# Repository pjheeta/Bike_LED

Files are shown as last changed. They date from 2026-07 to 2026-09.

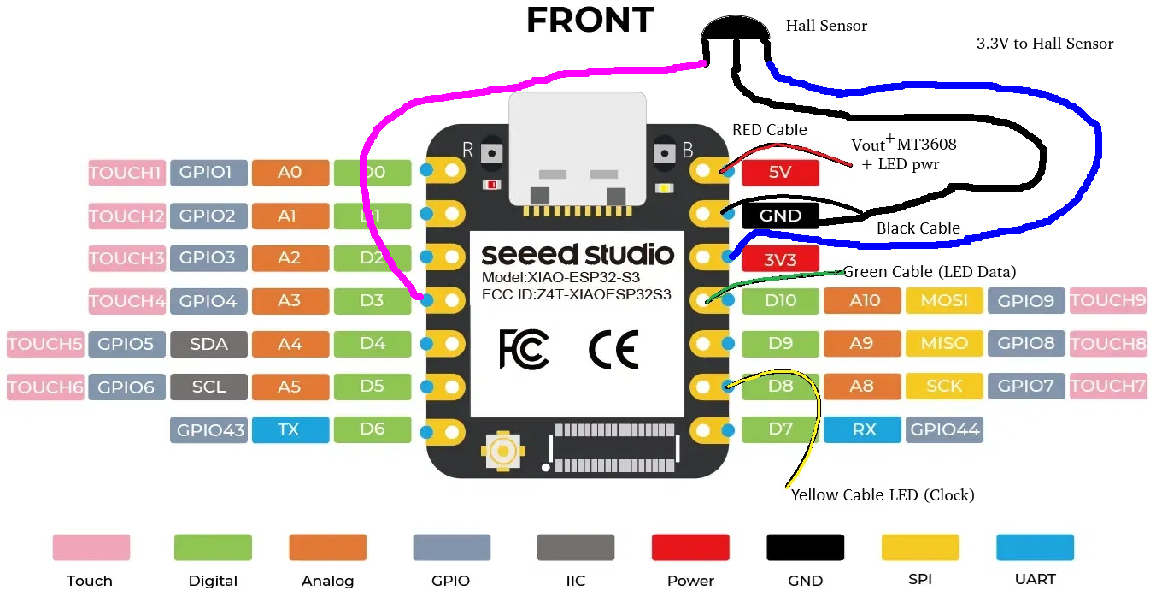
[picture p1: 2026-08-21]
ESP32S3 LED Pinout connection.jpg

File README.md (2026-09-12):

# Burning Man LED Wheel

<p align="center">
  Spinning LED wheel animation
</p>

<p align="center">
  Super cool Burning Man wheel LEDs inspired by:
</p>
<p align="left">
  - <a href="https://www.youtube.com/watch?v=W3Gmv9J05eQ">Monkey Lights POV</a>
</p>
<p align="left">
  - Luca Schultz's project <a href="https://github.com/BikeBeamer/BikeBeamer">BikeBeamer</a> 
</p>
<p align="left">
  - Adafruit Industries <a href="https://learn.adafruit.com/bike-wheel-pov-display/prep-leds-and-breadboard?view=all">BikeWheel POV Display with Pro Trinket</a> 
</p>

---

# Burning Man 2026 Update

<b>The project was a partial failure</b>
- The POV (Persistence of Vision) system did not work.   The Magnet / Hall Sensor Solution was a horrible Idea.    The magnets were not strong enough to trigger the hall sensor and mounting Magnets to the Bike was not practical.
- The industrial ABS boxes could not be secured with even two industrial strength zip ties.    The Playa was not an even ground and the the force of the bike wheels hitting the Playa released the boxes from the zip ties,  resulting in the ABS boxes from being ejected from the bike, and causing the wires to be broken. 
- The 26 AWG wires constantly broke, expecially from the Strip to Strip connecitons.   Detailed soldering on the Playa was not possible, and it was tiem consuming. 
- ESP Wi-Fi was not operational while using the LIPO batteries.   Wi-Fi worked with USB powered circuits, however I failed to test the completed system  powered by the Lipo batteres.    1 day before leaving for the burn, I relized the circuit required additioanl capaitors to power the circuit with the LIPO batteries.   I did not have a time to implement this, thus I had uploaded a 20 random patterns per bike wheel circuit to appear whenever the Bike LED system was turned on.

<b>Future changes to the system</b>
- 3D print the the enclosures and the LED Strips to directly attach to the bike spokes
- Use a Gyroscope, to measue rotations, eliminating the magnet
- Make the system modulate.     Do not rely on soldering connecitons, instead use physical connectors.   If the LED strips fails, it can easily be swapped out for a working one.

## ---

# Overview

POV (Persistence of Vision) LED display for a bike wheel. Animated images appear to float in the spinning wheel, visible from both sides. Controlled via WiFi from your phone — no app needed, although an Android app was created.

This project began withThis pdea of only having one LED strip per side. However, you would need to bike in excess of 20 mph to generate a stable image. Since this project was built for Burning Man, where the max speed is 5 mph on the playa, a single LED strip per arm wouldn't work.

After consulting with Luca Schultz (BikeBeamer builder), the design changed to **4 arms per wheel** with LED strips on both faces of each arm — 8 LED strips per wheel total. At around 5 mph, the image flashes 4 times per rotation, making basic shapes such as squares, circles, and the Man himself clearly visible.

My project uses a Vivi e-bike with 27.5" wheels. The **front wheel** uses LED strips with 144 LEDs/meter for maximum resolution, while the **back wheel** uses LED strips with 30 LEDs/meter for ambient glow patterns. Maybe in Burning Man 2027, both wheels will use the same LED counts.

⚠️ **Both Wheels are different!** The front wheel allows a longer LED strip. Due to e-bike design, the rear wheel has the hub motor — which means the distance from the hub to the rim is shorter. Henceforth, the spoke geometry is different, giving a shorter strip on the back wheel.

This version of Bike LED is for the 2026 Burning Man. A new repository will be created for the 2027 Burning Man project.

---

## Hardware

| Component | Notes |
|---|---|
| 2x XIAO ESP32-S3 | Main controller — WiFi + MicroPython. One per wheel. |
| SK9822 LED strips (144 LEDs/m) | Black PCB, IP30 — Front wheel: 8 strips × 27 LEDs = 216 LEDs total |
| SK9822 LED strips (30 LEDs/m) | Black PCB, IP30 — Rear wheel: 8 strips × 7 LEDs = 56 LEDs total |
| 3x LiPo 3.7V 2000mAh | 2x per front wheel (parallel for more capacity) + 1x rear wheel. All removable nightly for charging via JST connector. |
| 3x TP4056 USB-C | LiPo charger with protection circuit — one per battery |
| 2x MT3608 boost converter | Steps 3.7V LiPo up to 5.07V for LEDs and XIAO. LEDs require 5V to operate correctly. |
| 2x A3144 hall effect sensor | Rotation sync — fires one interrupt per revolution via falling edge trigger |
| 2x 1N5400 Schottky diode | One per positive wire on front wheel parallel battery pair — prevents cross-charging between batteries if voltage mismatch is present |
| 2x 6mm neodymium magnet | Mounts on fork dropout (stationary), triggers hall sensor once per rotation |
| 8x Aluminum flat bar 1/8" × 1/2" | LED arm material. Length depends on spoke measurement — cut after measuring actual bike. 4 per wheel. |
| 2x ABS enclosure 80×50×26mm | Hub-mounted via velcro + zip tie, houses all electronics |
| 2x SPST rocker switch 10×15mm | Kill switch — mounted on long side wall of enclosure |
| Kapton/polyimide tape | Applied between LED strip and aluminum bar to prevent electrical shorts |
| Velcro straps 3/4" | Secures enclosure to hub, secures components inside enclosure |
| Zip ties | Secures LED arms to spokes at hub end and rim end |
| Hot glue | Seals wire exit holes against playa dust |
| MG Chemicals 419D | Conformal coat — applied to all boards after testing is complete |

---

## Four-Arm Design

Both wheels use the same 4-arm layout — arms mounted at 90° intervals around the wheel, giving 4 image flashes per rotation at playa speed.

```
        ARM 1 (0°)
    ● ● ● ● ● ● ●      ← LEDs face right (A face)
    ═══════════════     ← Aluminum bar
    ● ● ● ● ● ● ●      ← LEDs face left  (B face — reversed in firmware)
            │
ARM 4 ══ HUB ══ ARM 2   ← XIAO + battery enclosure velcro'd to hub
            │
        ARM 3 (180°)
```

### Front Wheel — 144 LEDs/m

- **4 arms** at 90° apart
- **2 strips per arm** — A face (front) and B face (back)
- **27 LEDs per strip** at 144/m = 187mm (~7.4") per arm
- **216 LEDs total** across 8 strips
- **Daisy chain order:** XIAO → A1(1-27) → B1(28-54) → A2(55-81) → B2(82-108) → A3(109-135) → B3(136-162) → A4(163-189) → B4(190-216)

**LED table:**

| Strip | Start LED | End LED | Arm | Face |
|---|---|---|-----|---|
| A1 | 1 | 27 | Arm 1 | Front |
| B1 | 28 | 54 | Arm 1 | Back (reversed) |
| A2 | 55 | 81 | Arm 2 | Front |
| B2 | 82 | 108 | Arm 2 | Back (reversed) |
| A3 | 109 | 135 | Arm 3 | Front |
| B3 | 136 | 162 | Arm 3 | Back (reversed) |
| A4 | 163 | 189 | Arm 4 | Front |
| B4 | 190 | 216 | Arm 4 | Back (reversed) |

⚠️ **Back face strips (B1, B2, B3, B4) must be reversed in firmware.** The B strip runs rim → hub (opposite direction to the A strip), so the image would appear upside down without reversal. This is handled automatically in `frames.py` via `list(reversed(...))`.

**Animations:** Circle, square, cross, rainbow — simple geometric shapes chosen specifically because they are symmetric (look identical from both sides of the wheel) and clearly visible at 5 mph playa speeds.

---

### Rear Wheel — 30 LEDs/m

- **4 arms** at 90° apart
- **2 strips per arm** — A face (front) and B face (back)
- **7 LEDs per strip** at 30/m = ~233mm per arm
- **56 LEDs total** across 8 strips
- **Purpose:** Ambient glow and simple patterns — not detailed POV images
- Rear wheel has hub motor which shortens effective spoke length vs front wheel
- At 30 LEDs/m resolution is too low for detailed images — but rainbow, solid color, and simple shapes look great at any speed

**Powered by:** 1x 2000mAh LiPo — lighter draw than front wheel, single battery is sufficient.

---

## Power Architecture

⚠️ **Two completely separate circuits — never combine them.**

**Riding circuit (wheel spinning):**
```
LiPo → [1N5400 diode] → MT3608 (5.07V) → XIAO + LED strips
```
*(Front wheel: 2x LiPo in parallel via diodes. Rear wheel: single LiPo, no diodes needed.)*

**Charging circuit (parked at camp):**
```
USB-C wall charger → TP4056 → LiPo battery
```
The TP4056 is **never** in the riding circuit. Each LiPo unplugs via JST connector for individual overnight charging.

---

## Burning Man Notes

- **Balance** — mount battery as close to hub center as possible to minimize vibration
- **Don't tap the e-bike battery** — keep LED system on its own LiPo, modular and safe
- **Nightly charging** — LiPo velcro-mounts to enclosure floor, unplugs via JST in seconds
- **Playa-proof** — hot glue all wire exits, apply MG Chemicals 419D conformal coat to all boards after testing
- **Kill switch** — rocker switch on enclosure wall cuts all power instantly
- **Safety mode** — if hall sensor stops triggering, firmware automatically switches to alternating white safety LEDs

---

## Built With

- MicroPython
- Thonny (MicroPython Code IDE)
- VS Code
- MarkEdit and the home extension MarkView
- Cool people such as Luca (BikeBeamer)
- Blood, sweat, and tears
- claude.ai for tips, explanation, lessons, and making me order the wrong parts
- [StackEdit](https://stackedit.io/) for this README

---

## Files

| File | Purpose |
|---|---|
| `main.py` | Main loop — WiFi server + POV timing. Auto-runs on boot |
| `apa102.py` | SPI driver for SK9822/APA102 LED strip |
| `hall_sync.py` | Hall sensor interrupt handler — measures rotation period |
| `frames.py` | Frame data — circle, square, cross, rainbow animations |
| `convertImage.py` | Laptop-side script — converts PNG to `frames.py` format |
| `BOM.txt` | Full bill of materials with sources and prices |

**main.py flow:**
```
Boot → Start WiFi + Web Server
         ↓
Loop → Check web requests every 100ms
         ↓
      Wheel spinning? No → LEDs off (safety)
         ↓ Yes
      Get rotation period from hall sensor
         ↓
      Display 60 columns timed to rotation speed
         ↓
      Repeat forever
```

**apa102.py SPI chain:**
```
XIAO GPIO9 (MOSI) ──→ DI ──→ LED 1 ──→ LED 2 ──→ ... ──→ LED 216
XIAO GPIO7 (SCK)  ──→ CI ──→ LED 1 ──→ LED 2 ──→ ... ──→ LED 216

Every strip.show() call sends:
[00 00 00 00]        ← Start frame — "attention LEDs!"
[FF bb gg rr]        ← LED 1 color (4 bytes — note B,G,R order not R,G,B)
...repeat per LED...
[FF FF FF FF...]     ← End frame — "that's all!"
```

**hall_sync.py flow:**
```
Magnet passes sensor
        ↓
Pin goes HIGH → LOW (falling edge)
        ↓
Hardware interrupt fires instantly
        ↓
_on_trigger() records timestamp + period + count
        ↓
main.py reads period_us → calculates column timing
main.py reads rotation_count → advances animation frame
main.py calls is_spinning() → decides whether to show LEDs
```

---

## WiFi Control

The XIAO acts as its own WiFi access point — no internet or router needed.

1. Connect phone to **BikeWheel** network (password: `burningman`)
2. Open Android app or browser → `192.168.4.1`
3. Control on/off, brightness, speed, safety mode, select animation frame

---

## Animation Frames

Originally planned: Nyan Cat, Angine de Poitrine polka dot mask, Joe's face.

After consulting with Luca (BikeBeamer) and calculating that 5 mph playa speed only gives ~1 rotation/second with a single arm, the design changed to 4 arms and simple geometric shapes that read clearly at low flash rates:

- 🔴🔵 **Test pattern** — alternating red/blue columns (confirms POV timing)
- ⭕ **Circle** — glowing cyan ring floating in the wheel
- 🟧 **Square** — orange square outline
- ✚ **Cross** — pink plus sign
- 🌈 **Rainbow** — full color waterfall, works at any speed

Images will still be added for testing and showing off to people at camp. 😄

---

## Image Conversion Pipeline

Design artwork at **60 × 27 pixels** in any image editor → run `convertImage.py` on laptop → upload `frames.py` to XIAO via Thonny → image appears on spinning wheel.

---

## License

MIT

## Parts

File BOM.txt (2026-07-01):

XIAO ESP32-S3 (x2) — search: Seeed Studio XIAO ESP32S3 — ~$10-13 each

LiPo Battery 3.7V 2000mAh (x2) — search: 3.7V 2000mAh LiPo flat battery JST connector — ~$8-12 each

TP4056 Charger Board (x2) — search: TP4056 charging module with protection — ~$1-2 each

MT3608 Boost Converter (x2) — search: MT3608 DC-DC boost converter module — ~$1-2 each

Hall Effect Sensor A3144 (pack of 10) — search: A3144 hall effect sensor module — ~$5-7

Neodymium Disc Magnets 6mm (pack of 20) — search: 6mm x 2mm neodymium disc magnets — ~$6-8

Carbon Fiber Flat Strip — search: carbon fiber flat strip 3mm 300mm — ~$10-15

MG Chemicals 419D Conformal Coat — search: MG Chemicals 419D conformal coating — ~$15-18

Silicone Wire 24 AWG — search: 24 AWG silicone wire kit multicolor — ~$8-10

JST-SH Connectors — search: JST SH 1.0mm connector kit — ~$8-10

Heat Shrink Tubing — search: heat shrink tubing assorted sizes kit — ~$8-10

Kill Switch (add both — button for riding, rocker for hard off)

Momentary Tactile Push Button (pack of 20) — search: 6mm momentary tactile push button switch — ~$5 | Mounts on hub enclosure, one-handed toggle while riding

Mini Rocker Switch (pack of 10) — search: mini rocker switch ON OFF SPST 3A — ~$7 | Hard power cut on the power line, no reboot needed if wired after TP4056

SK9822 LED Strip, 5m, Black PCB, IP30 
Slip ring, 6-wire, 2A/channel (metal housing preferred)

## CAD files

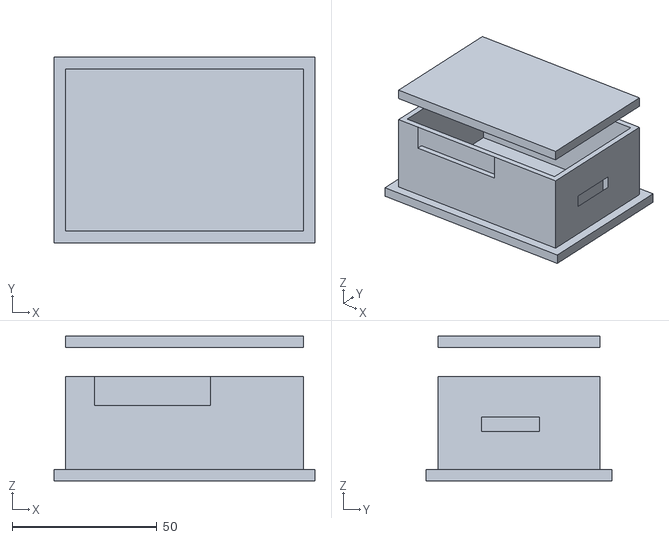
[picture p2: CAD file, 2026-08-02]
Hardware/bikewheel_enclosure.stl
90.0 x 64.0 x 50.0

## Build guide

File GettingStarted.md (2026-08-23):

# BikeWheel Project — Command Reference
## Pawan Heeta | Burning Man 2026

---

## 1. LINUX SETUP (Ubuntu/Mint)

### Add user to dialout group (fixes USB permission errors)
```bash
sudo usermod -a -G dialout $USER
# Then reboot
```

### Add esptool to PATH
```bash
echo 'export PATH=$PATH:~/Library/Python/3.9/bin' >> ~/.zshrc
source ~/.zshrc
```

### Install esptool
```bash
pip3 install esptool --break-system-packages
esptool.py version  # confirm 4.12.0+
```

---

## 2. FLASHING MICROPYTHON FIRMWARE

### Download firmware
- URL: https://micropython.org/download/SEEED_XIAO_ESP32S3/
- Get latest preview .bin file

### Put XIAO in bootloader mode
1. Hold BOOT button
2. Press and release RESET
3. Release BOOT

### Flash firmware
```bash
# Erase first
esptool.py --port /dev/ttyACM0 erase_flash

# Flash MicroPython
esptool.py --port /dev/ttyACM0 write_flash 0 SEEED_XIAO_ESP32S3-XXXXXXXX.bin
```

### Find port on Linux
```bash
ls /dev/tty*
# Look for /dev/ttyACM0 or /dev/ttyUSB0
```

---

## 3. THONNY SETUP

- Interpreter: MicroPython (ESP32)
- Port: /dev/ttyACM0 (or /dev/ttyUSB0)
- Tools → Options → Interpreter → Port dropdown

---

## 4. WEBREPL SETUP (Wireless file upload)

### Enable WebREPL on XIAO (run once in Thonny shell)
```python
import webrepl_setup
# Press E to enable
# Set password: bikewheel
```

### Update boot.py to auto-start WebREPL with password
```python
f = open('boot.py', 'w')
f.write("import webrepl\nwebrepl.start(password='bikewheel')\n")
f.close()
```

### Download WebREPL CLI tool
```bash
wget https://raw.githubusercontent.com/micropython/webrepl/master/webrepl_cli.py
```

### Upload a single file wirelessly
```bash
# Connect laptop to BikeWheel WiFi first (password: burningman)
python3 ~/Downloads/webrepl_cli.py -p bikewheel ~/Bike_LED/Front_ESP/main.py 192.168.4.1:/main.py
```

### Download WebREPL GUI (offline browser client)
```bash
wget https://raw.githubusercontent.com/micropython/webrepl/master/webrepl.html
xdg-open webrepl.html
# Connect to ws://192.168.4.1:8266
```

---

## 5. UPLOAD SCRIPTS

### Front ESP upload script (frontUL.sh)
```bash
#!/bin/bash
IP=192.168.4.1
PASS=bikewheel
DIR=~/Bike_LED/Front_ESP

for f in main.py apa102.py hall_sync.py frames.py espnow_tx.py index.html; do
    python3 ~/Downloads/webrepl_cli.py -p $PASS $DIR/$f $IP:/$f
    echo "Uploaded $f"
done
```

### Back ESP upload script (backUL.sh)
```bash
#!/bin/bash
IP=192.168.4.1
PASS=bikewheel
DIR=~/Bike_LED/Back_ESP

for f in main.py apa102.py espnow_rx.py; do
    python3 ~/Downloads/webrepl_cli.py -p $PASS $DIR/$f $IP:/$f
    echo "Uploaded $f"
done
```

### Make scripts executable
```bash
chmod +x ~/Bike_LED/Front_ESP/frontUL.sh
chmod +x ~/Bike_LED/Back_ESP/backUL.sh
```

### Run upload scripts
```bash
# Connect to BikeWheel WiFi first
./frontUL.sh

# Connect to BikeWheelRear WiFi first
./backUL.sh
```

---

## 6. USEFUL MICROPYTHON SHELL COMMANDS (in Thonny)

### List files on device
```python
import os
os.listdir()
```

### Check boot.py contents
```python
f = open('boot.py', 'r')
print(f.read())
f.close()
```

### Quick LED test (27 LEDs red)
```python
from machine import SPI, Pin
spi = SPI(1, baudrate=8_000_000, polarity=0, phase=0, sck=Pin(7), mosi=Pin(9))
data = bytearray(4)
for i in range(27):
    data += bytes([0xE8, 0, 0, 255])
data += bytes([0xFF] * 3)
spi.write(data)
```

### Quick hall sensor test
```python
from machine import Pin
import time
hall = Pin(4, Pin.IN, Pin.PULL_UP)
while True:
    print(hall.value())
    time.sleep_ms(100)
```

### Start WebREPL manually
```python
import webrepl
webrepl.start(password='bikewheel')
```

### Check MT3608 voltage (use multimeter on VOUT+ and GND)
# Target: 5.07V

---

## 7. WIFI NETWORKS

| Network | Password | XIAO  | IP | Use |
|---|---|---|---|---|
| BikeWheel | burningman | Front | 192.168.4.1  | Control + WebREPL |
| BikeWheelRear  | burningman | Rear  | 192.168.4.1  | WebREPL only |

---

## 8. WEB CONTROL ENDPOINTS (Front XIAO)

| Endpoint | Action |
|---|---|
| / | PWA control page |
| /on | LEDs on |
| /off | LEDs off |
| /next | Next animation pattern |
| /brightness/N | Set brightness (1-31) |
| /ping | Health check |
| /status | JSON status + RPM |

---

## 9. FILE STRUCTURE

```
~/Bike_LED/
├── Front_ESP/
│   ├── main.py          # POV engine + WiFi + ESP-NOW
│   ├── apa102.py        # SK9822 LED driver
│   ├── hall_sync.py     # A3144 hall sensor driver
│   ├── frames.py        # POV animation frames
│   ├── espnow_tx.py     # Broadcasts RPM to rear XIAO
│   ├── index.html       # PWA control page
│   └── frontUL.sh       # Wireless upload script
├── Back_ESP/
│   ├── main.py          # Ambient glow + ESP-NOW receiver
│   ├── apa102.py        # SK9822 LED driver
│   ├── espnow_rx.py     # Receives RPM from front XIAO
│   └── backUL.sh        # Wireless upload script
├── Android/
│   └── BikeWheelApp.zip # Android APK source
├── Sample_Code/         # Test scripts
├── Guides/              # PDFs and docs
├── Hardware/            # STL and datasheets
└── Firmware/            # MicroPython .bin files
```

---

## 10. HARDWARE PINOUT (Front XIAO ESP32-S3)

| Pin | Label | Connected to |
|-----|---|---|
| 1 | 5V | MT3608 VOUT+ + LEDs |
| 2 | GND | Common ground |
| 3 | 3V3 | Hall sensor VCC |
| 4 | D10/GPIO9  | LED DATA (MOSI) |
| 6 | D8/GPIO7 | LED CLK (SCK) |
| 11  | D3/GPIO4 | Hall sensor OUT |

---

## 11. LED CONFIGURATION

| Wheel | Strips | LEDs/strip | Total LEDs | Strip type |
|---|---|---|---|---|
| Front | 8 | 27 | 216 | SK9822 144/m  |
| Rear  | 4 | ~10 | 40 | SK9822 30/m |

Daisy chain order (front):
XIAO → A1→B1→A2→B2→A3→B3→A4→B4

---

## 12. POWER CIRCUIT (Front Wheel)

```
LiPo1+ → [1N5400 diode] \
                          → [ROCKER SWITCH] → MT3608 IN+ → MT3608 VOUT+(5.07V) → XIAO 5V → LEDs
LiPo2+ → [1N5400 diode] /

LiPo1- ──────────────────────────────────────────────────────────────────────────────→ GND
LiPo2- ──────────────────────────────────────────────────────────────────────────────→ GND
```

⚠️ TP4056 charging circuit is completely separate — never connect to riding circuit
⚠️ Rocker switch on positive wire only, never on ground

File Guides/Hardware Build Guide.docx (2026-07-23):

# POV Bike Wheel LED Display — Hardware Build Guide

Target: 26" cruiser test bike / future AMYET fat tire e-bike

# Power Architecture

IMPORTANT: There are two completely separate circuits. Never combine them.

## Riding Circuit (wheel spinning):

LiPo battery → MT3608 boost converter (5.07V) → XIAO ESP32-S3 + LED strip

## Charging Circuit (parked at camp):

USB-C wall charger → TP4056 charger board → LiPo battery

The TP4056 is NEVER in the riding circuit. It is a standalone charger only. At camp: unplug LiPo from MT3608, plug into TP4056 to charge overnight.

# Key Hardware Decisions

Component | Choice | Notes
MCU | XIAO ESP32-S3 | WiFi, MicroPython, tiny 21×17mm
LEDs | SK9822 144/m Black PCB IP30 | Dual clock = SPI compatible
Power | LiPo 3.7V 2000mAh 654065 | JST PH 2.0mm connector
Boost converter | MT3608 | Adjusted to 5.07V output
Charger | TP4056 Type-C | Charging only — not in ride circuit
Hall sensor | A3144 | GPIO4 (D3), PULL_UP, IRQ_FALLING
Arm material | 1/8" × 1/2" aluminum flat bar | Home Depot ~$6 for 3ft
Connectors | Pre-made JST PH 2.0mm cables | Do NOT use crimp tool — buy pre-made

# Wiring Reference

## SK9822 Wire Colors

Wire | Signal | XIAO Pin
Red | 5V Power | 5V pin
Black | GND | GND pin
Yellow | CI (Clock) | D8 / GPIO7
Green | DI (Data) | D10 / GPIO9

## Hall Sensor (A3144) — flat face toward you, legs down

Leg | Label | Connect to
Left | VCC | XIAO 3.3V
Middle | GND | XIAO GND
Right | OUT | XIAO D3 (GPIO4)

## Full Wiring Chain

LiPo (+) → MT3608 VIN+

LiPo (-) → MT3608 VIN-

MT3608 VOUT+ → XIAO 5V

MT3608 VOUT- → XIAO GND

MT3608 VOUT+ → LED strip 5V (Red wire)

MT3608 VOUT- → LED strip GND (Black wire)

XIAO D10 → LED strip DI (Green wire)

XIAO D8 → LED strip CI (Yellow wire)

XIAO 3.3V → Hall sensor VCC (Left leg)

XIAO GND → Hall sensor GND (Middle leg)

XIAO D3 → Hall sensor OUT (Right leg)

# Phase 1 — Build the LED Arm

1. Cut aluminum flat bar (1/8" × 1/2") to measured spoke length

2. File the mounting face lightly (3-4 passes) to roughen surface for adhesion

3. Wipe with isopropyl alcohol, let dry 30 seconds

4. Cut SK9822 LED strip to match — count LEDs, cut only at marked scissor points

5. Peel backing, press LED strip firmly onto filed face, hold 60 seconds

6. Leave data-in end (DI/CI/5V/GND pads) exposed at hub end of arm

# Phase 2 — Wire the Hub Assembly

Do NOT use breadboard for final build — solder all connections directly.

1. Set MT3608 to 5V FIRST — connect LiPo only, measure VOUT, turn trim pot (many turns) until reading 5.0-5.1V. 5.07V is perfect.

2. Solder all connections per wiring chain above

3. Hall sensor: solder VCC and GND legs permanently, leave OUT leg on temporary wire until GPIO pin confirmed

4. Bench test: power on from LiPo, confirm XIAO boots, LEDs light, hall sensor counts rotations

# Phase 3 — Mount to Wheel

1. Position aluminum bar radially spanning two adjacent spokes (hub to rim)

2. Zip tie at hub end and rim end — between LEDs, not over them

3. Mount hall sensor at hub END of arm, flat face pointing toward fork leg

4. Stack 2-3 neodymium magnets, mount to fork leg at exact same height as hall sensor

5. Spin wheel by hand — confirm sensor passes within 3-5mm of magnet each rotation

6. Mount XIAO + MT3608 + LiPo near hub with velcro + zip ties

# Troubleshooting Reference

Symptom | Likely Cause | Fix
LEDs don't light | Wrong end of strip connected | Check arrow — connect to DI/CI input end
LEDs don't light | XIAO inserted backwards | Flip XIAO around
Only some LEDs light / wrong colors | Loose DI or CI wire | Wiggle wires, resolder
Hall sensor always reads 1 | Breadboard connection issue | Solder directly — no breadboard
Hall sensor always reads 0 | Magnet too close or wrong pole | Move magnet away, or flip it over
MT3608 voltage not changing | Need many pot turns | Turn slowly, many full rotations required
XIAO resets while riding | Power brownout | Check MT3608 voltage under load

# Lessons Learned

- Breadboards are unreliable for this build — solder everything directly
- Pre-made JST PH 2.0mm cables only — do NOT buy crimping tools or loose connector kits
- TP4056 is charge-only — never in the riding power circuit
- Check LED strip direction — must connect to input (DI/CI) end, not output (DO/CO)
- XIAO orientation matters — easy to insert backwards on a breadboard
- MT3608 trim pot needs many turns — not a small adjustment
- Carbon fiber bar is impractical — use 1/8" × 1/2" aluminum flat bar instead
- 30 LEDs/m strip is wrong density — must order BTF-5V-144L-B (144/m)

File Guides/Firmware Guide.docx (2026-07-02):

POV Bike Wheel

Firmware & Upload Guide

MicroPython · VS Code · XIAO ESP32-S3 · Two-arm build

This guide covers the two-arm build: two LED strips per arm, four strips total, daisy-chained on a single SPI bus. No extra code complexity — the daisy-chain means all strips see the same data automatically.

# Part 1 — Set Up VS Code

Write all code on your MacBook in VS Code, upload to the XIAO over USB-C.

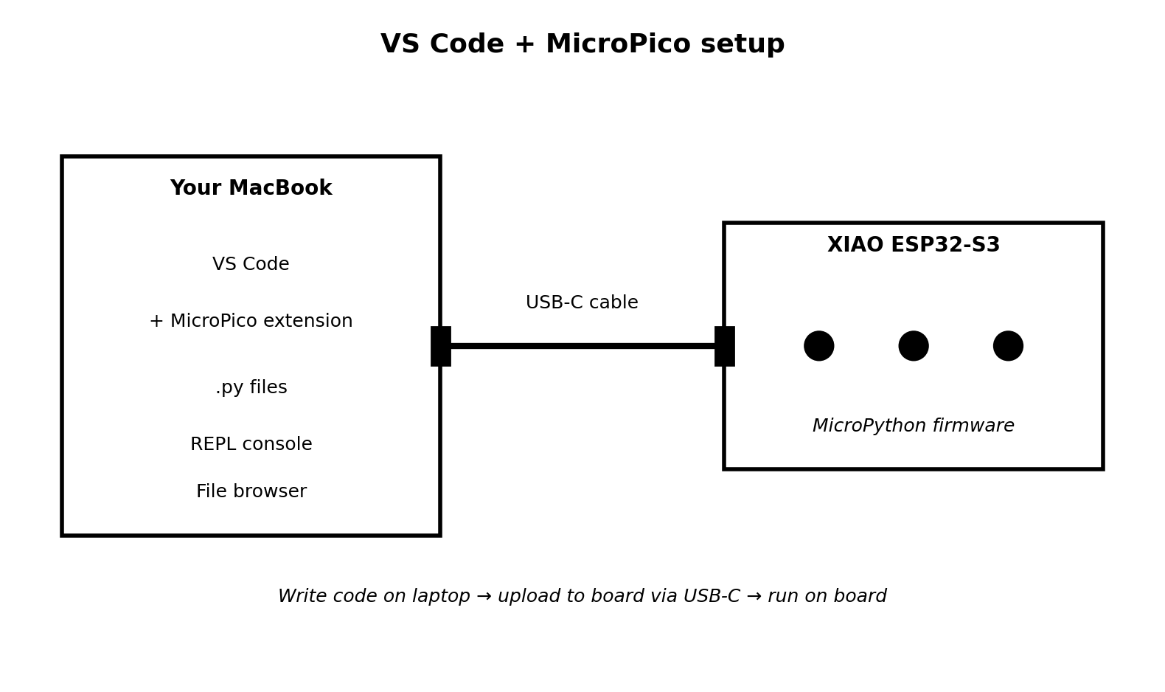
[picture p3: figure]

Figure 1 — VS Code to XIAO via USB-C

## Step 1.1 — Install the MicroPico extension

- VS Code → Extensions (⌘+Shift+X) → search MicroPico by paulober → Install
- A connection status indicator appears in the bottom status bar

## Step 1.2 — Flash MicroPython onto the XIAO

1. Download Generic ESP32-S3 MicroPython firmware (.bin) from micropython.org/download
2. Connect XIAO via USB-C
3. Bootloader mode: hold BOOT, tap RESET, release BOOT
4. VS Code Command Palette (⌘+Shift+P) → MicroPico: Flash MicroPython → select the .bin file
5. Reset board — MicroPico status bar shows Connected

💡 Use a data-capable USB-C cable, not a charge-only cable. If status shows Disconnected, check the cable first.

# Part 2 — File Structure

Same four files as a single-arm build. The two-arm change is entirely in the wiring — the daisy-chain handles the second strip at the hardware level, so the firmware doesn't know or care how many strips are physically connected.

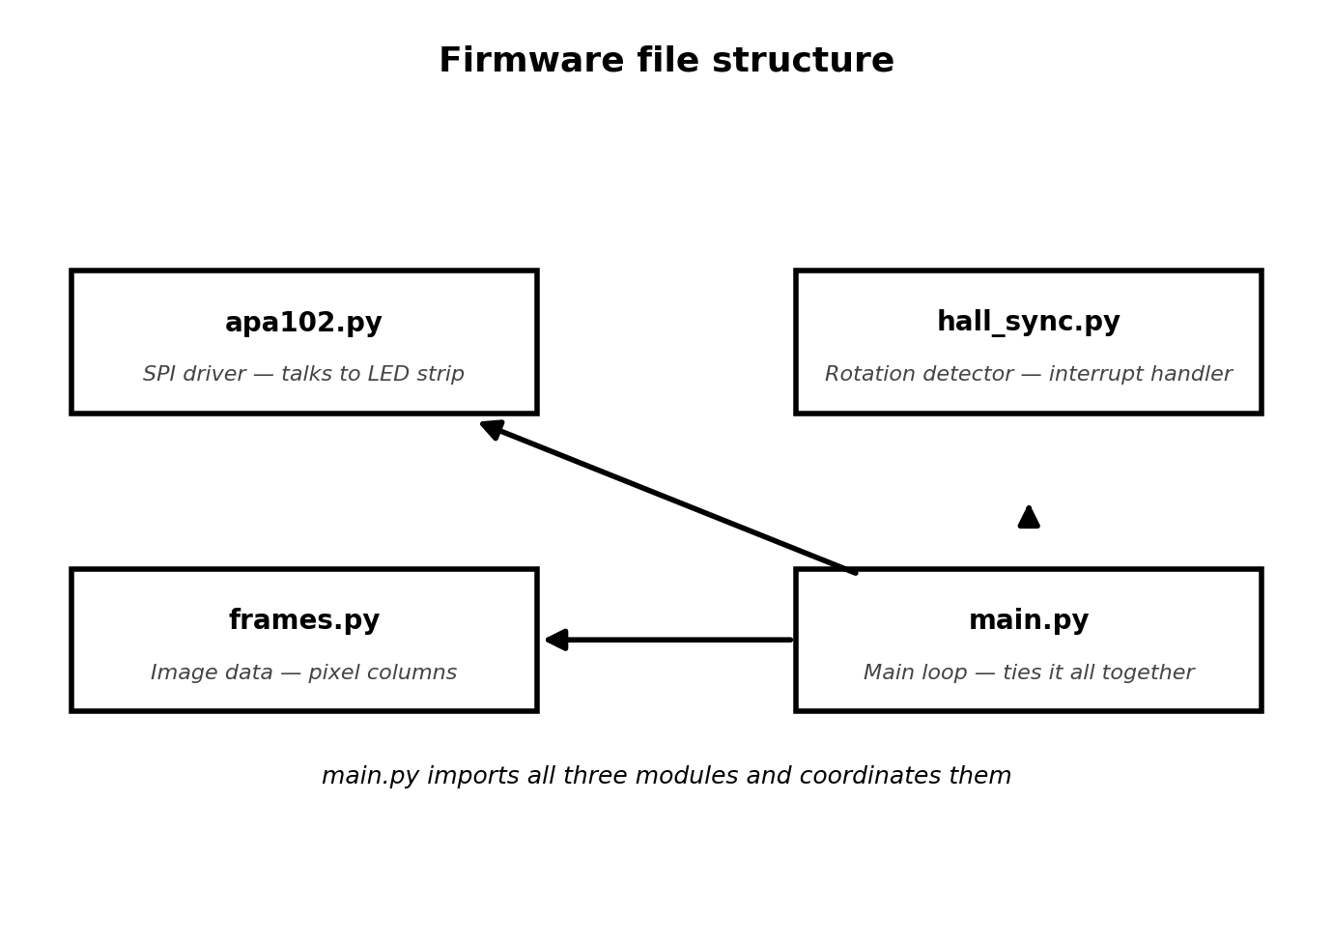
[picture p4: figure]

Figure 2 — four files, same structure as single-arm build

- apa102.py — SPI driver, unchanged from single-arm
- hall_sync.py — rotation interrupt, unchanged
- frames.py — your artwork, unchanged
- main.py — main loop, one small addition: NUM_LEDS doubles to 78 (39 per arm × 2 arms)

💡 Because the strips are daisy-chained, writing 78 pixels in one SPI transaction lights the first 39 LEDs on strip 1 and the next 39 on strip 2 automatically. No extra SPI calls needed.

# Part 3 — Write apa102.py (LED Driver)

Identical to single-arm. The SPI driver sends a single stream of pixel data — the daisy-chain distributes it across both strips transparently.

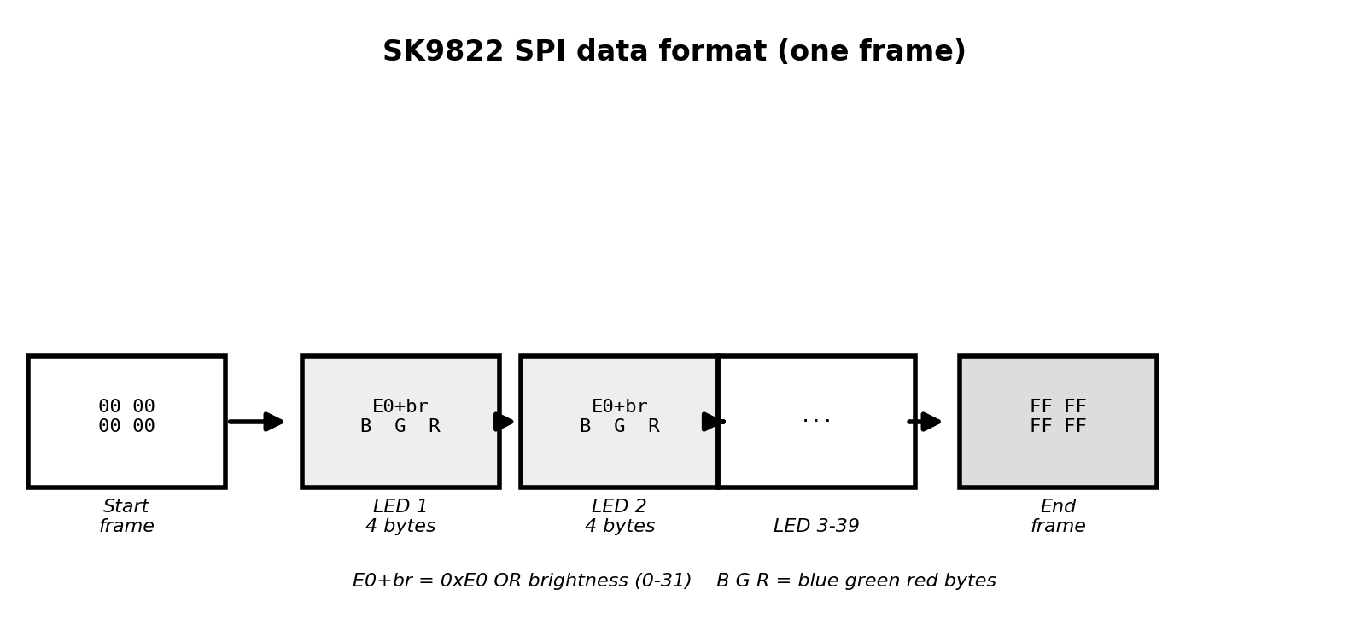
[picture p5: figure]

Figure 3 — SK9822 SPI data format, same for 2 or 4 strips

## The code — unchanged from single-arm

from machine import SPI, Pin

class APA102:

def __init__(self, spi_id=1, sck_pin=7, mosi_pin=9,

num_leds=78, brightness=20): # 78 = 39 x 2 arms

self.num_leds = num_leds

self.brightness = brightness & 0x1F

self.spi = SPI(spi_id, baudrate=8_000_000,

polarity=0, phase=0,

sck=Pin(sck_pin), mosi=Pin(mosi_pin))

def show(self, pixels):

data = bytearray(4) # start frame

for r, g, b in pixels:

data += bytes([0xE0 | self.brightness, b, g, r])

data += bytes([0xFF] * ((self.num_leds // 16) + 1))

self.spi.write(data)

def off(self):

self.show([(0, 0, 0)] * self.num_leds)

## Test it

from apa102 import APA102

strip = APA102(num_leds=78)

strip.show([(255, 0, 0)] * 78) # all 4 strips should go red

strip.off()

💡 If only the first two strips light up, the daisy-chain connection between strip 2 and strip 3 has a wiring issue. Check the data-out → data-in solder joint between them.

# Part 4 — Write hall_sync.py (Rotation Detector)

Completely unchanged from single-arm. One sensor, one magnet, one interrupt per rotation regardless of arm count.

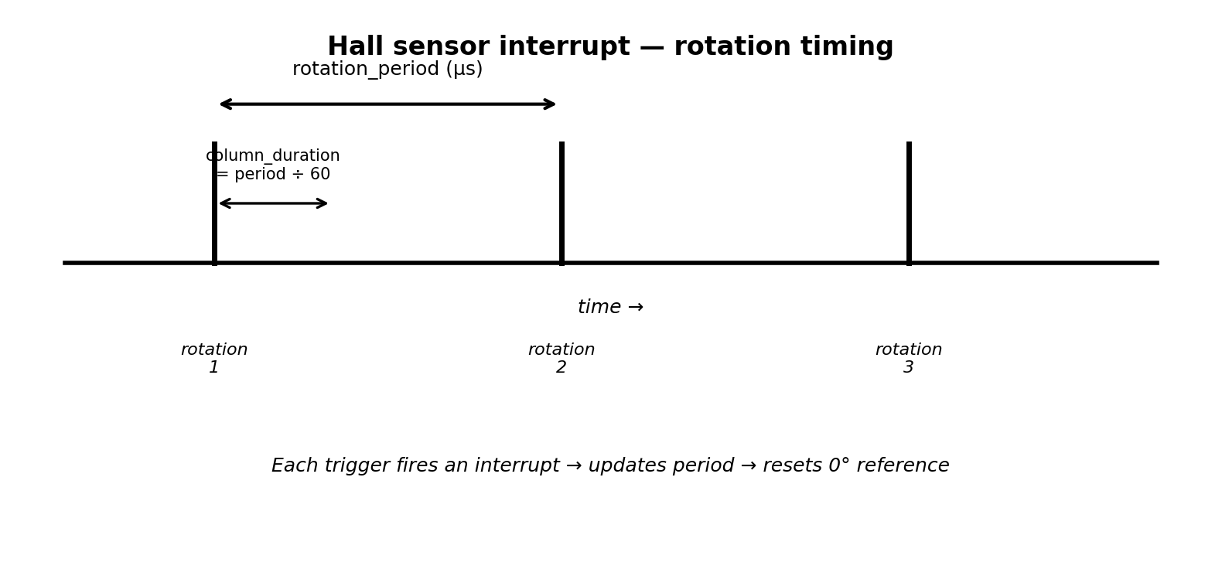
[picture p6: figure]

Figure 4 — rotation timing, same for any number of arms

from machine import Pin

import time

class HallSync:

def __init__(self, pin_num=3):

self.pin = Pin(pin_num, Pin.IN, Pin.PULL_UP)

self.last_time = time.ticks_us()

self.period_us = 0

self.rotation_count = 0

self.pin.irq(trigger=Pin.IRQ_FALLING,

handler=self._on_trigger)

def _on_trigger(self, pin):

now = time.ticks_us()

diff = time.ticks_diff(now, self.last_time)

if diff > 5000:

self.period_us = diff

self.last_time = now

self.rotation_count += 1

def get_period(self): return self.period_us

def is_spinning(self):

return time.ticks_diff(time.ticks_us(), self.last_time) < 1_000_000

## Test it

from hall_sync import HallSync

h = HallSync(pin_num=3)

# wave magnet past sensor — check count increases

print(h.rotation_count, h.period_us)

# Part 5 — Write frames.py (Image Data)

One key change for two-arm: each column now has 78 pixels (39 per arm) instead of 39. The first 39 pixels go to arm 1, the next 39 to arm 2 via daisy-chain.

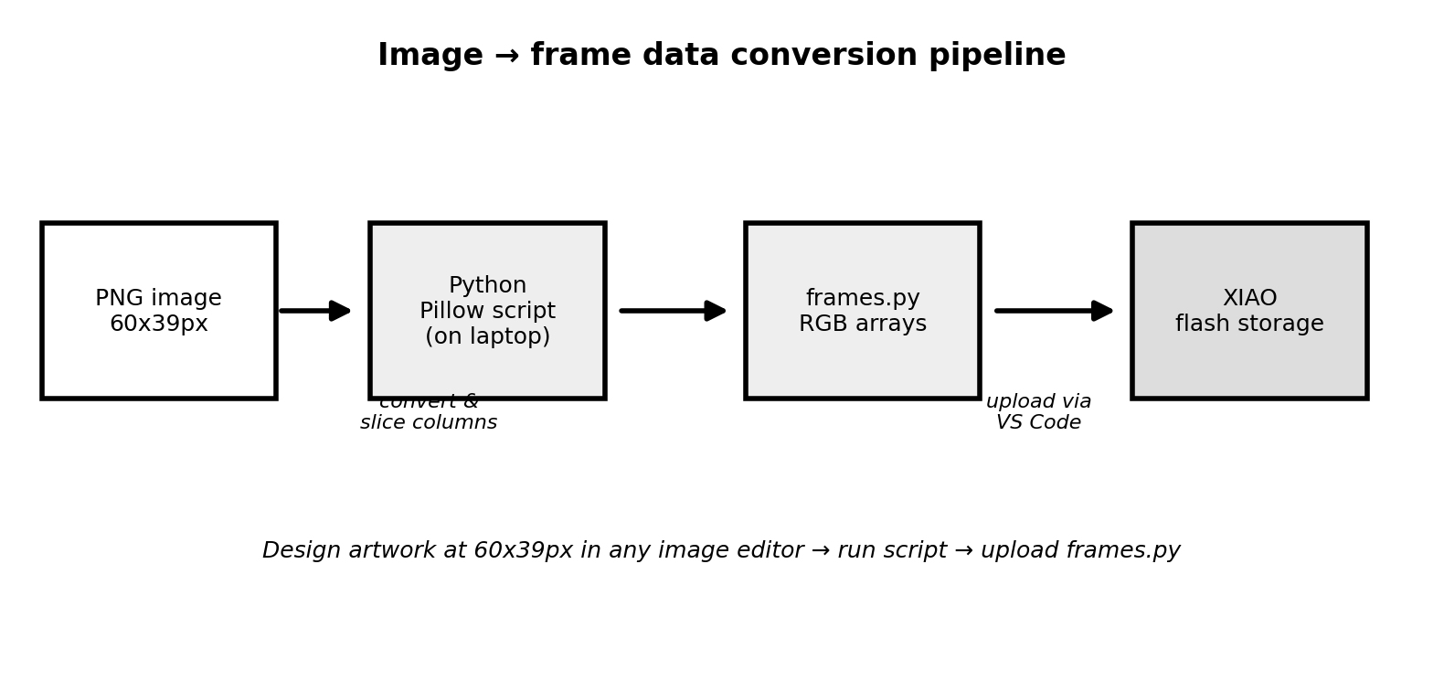
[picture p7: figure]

Figure 5 — image conversion pipeline, same process

## Test pattern — updated for 78 LEDs

NUM_COLUMNS = 60

NUM_LEDS = 78 # 39 per arm x 2 arms

LEDS_PER_ARM = 39

def make_test_frame():

frame = []

for col in range(NUM_COLUMNS):

color = (255, 0, 0) if col % 2 == 0 else (0, 0, 255)

# same pixel data repeated for both arms via daisy-chain

frame.append([color] * NUM_LEDS)

return frame

FRAMES = [make_test_frame()]

## Image converter — updated for 78 LEDs

Run this on your MacBook. Source image should be 60 x 78 pixels (60 columns x 78 LEDs). The top 39 rows go to arm 1, bottom 39 rows to arm 2.

from PIL import Image

NUM_COLUMNS = 60

NUM_LEDS = 78

def image_to_frame(path):

img = Image.open(path).convert('RGB')

img = img.resize((NUM_COLUMNS, NUM_LEDS))

frame = []

for col in range(NUM_COLUMNS):

column_pixels = []

for led in range(NUM_LEDS):

r, g, b = img.getpixel((col, led))

column_pixels.append((r, g, b))

frame.append(column_pixels)

return frame

def write_frames_file(paths, output='frames.py'):

with open(output, 'w') as f:

f.write(f'NUM_COLUMNS = {NUM_COLUMNS}\n')

f.write(f'NUM_LEDS = {NUM_LEDS}\n\n')

f.write('FRAMES = [\n')

for p in paths:

f.write(' ' + repr(image_to_frame(p)) + ',\n')

f.write(']\n')

write_frames_file(['my_logo.png'])

💡 Design your source image at 60 x 78 pixels. The top half (rows 0-38) maps to arm 1, bottom half (rows 39-77) maps to arm 2. For a symmetrical design both halves show the same image — for a creative build they can show different content.

# Part 6 — Write main.py (Main Loop)

Almost identical to single-arm. The only change is NUM_LEDS=78. Everything else — timing, frame advance, kill switch button, hall sync — is the same.

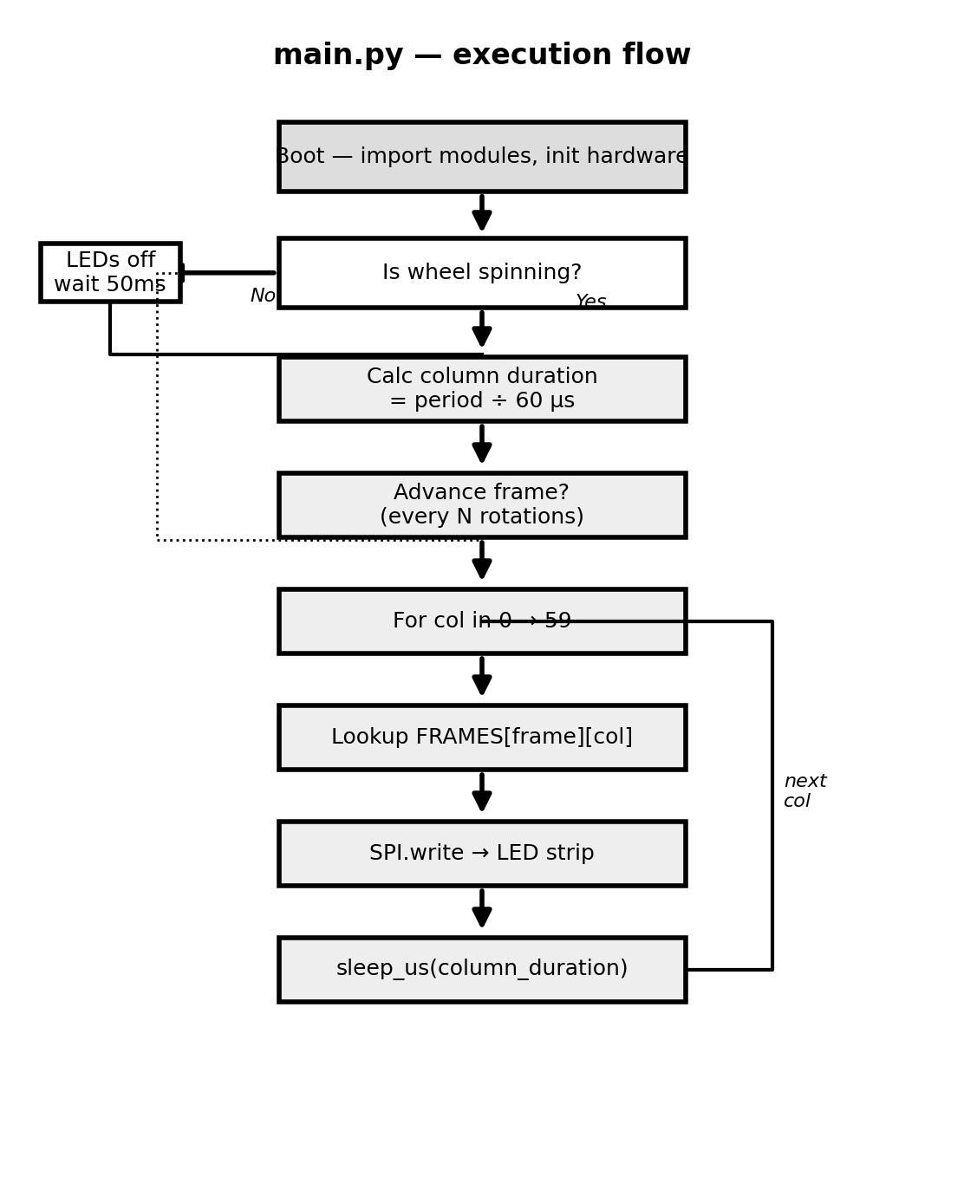
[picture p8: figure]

Figure 6 — main loop execution flow, unchanged

## The code

import time

from machine import Pin

from apa102 import APA102

from hall_sync import HallSync

from frames import FRAMES, NUM_COLUMNS, NUM_LEDS

strip = APA102(num_leds=NUM_LEDS, brightness=20) # 78 LEDs

hall = HallSync(pin_num=3)

button = Pin(4, Pin.IN, Pin.PULL_UP)

current_frame = 0

rot_at_last_frame = 0

ROTATIONS_PER_FRAME = 5

leds_on = True

last_btn = 0

def check_button():

global leds_on, last_btn

if button.value() == 0:

now = time.ticks_ms()

if time.ticks_diff(now, last_btn) > 300:

leds_on = not leds_on

if not leds_on: strip.off()

last_btn = now

while True:

check_button()

if not leds_on or not hall.is_spinning():

strip.off()

time.sleep_ms(50)

continue

period = hall.get_period()

if period == 0:

time.sleep_ms(10)

continue

if hall.rotation_count - rot_at_last_frame >= ROTATIONS_PER_FRAME:

current_frame = (current_frame + 1) % len(FRAMES)

rot_at_last_frame = hall.rotation_count

column_dur = period // NUM_COLUMNS

frame = FRAMES[current_frame]

for col in range(NUM_COLUMNS):

t0 = time.ticks_us()

strip.show(frame[col])

elapsed = time.ticks_diff(time.ticks_us(), t0)

remaining = column_dur - elapsed

if remaining > 0:

time.sleep_us(remaining)

# Part 7 — Upload All Files

## Upload order

6. Connect XIAO via USB-C — confirm MicroPico shows Connected
7. VS Code Explorer → MicroPico Device panel
8. Right-click each file → Upload to MicroPico
9. Upload order: apa102.py → hall_sync.py → frames.py → main.py
10. Press RESET on the XIAO — main.py runs automatically

💡 To update artwork only: regenerate frames.py on your laptop using the converter script, upload just frames.py, reset. The other three files stay on the board unchanged.

## What to expect on first boot with two arms

- Both arms light up simultaneously — the daisy-chain distributes data to all four strips in one SPI transaction
- Image appears twice per rotation (once per arm) — looks brighter and more defined than single-arm
- If one arm shows the image and the other shows nothing — check the data-out to data-in connection between strip 2 and strip 3
- If both arms show image but they look offset from each other — arm 2 is not mounted exactly 180° opposite arm 1, adjust its position

# Quick Troubleshooting

- Only first arm lights up → daisy-chain break between strip 2 data-out and strip 3 data-in
- Arms show image at different positions → arms not 180° apart, or hall sensor triggers inconsistently
- LEDs don't light at all → wrong SCK/MOSI pin numbers in APA102.__init__
- hall.rotation_count never increases → wrong GPIO pin or sensor wiring issue
- Image blurry → reduce NUM_COLUMNS from 60 to 40
- Board resets while spinning → power brownout, check MT3608 output under load
- ModuleNotFoundError → file not uploaded to board, re-upload via MicroPico file browser
- SyntaxError on boot → typo in one of the .py files, check REPL output for line number

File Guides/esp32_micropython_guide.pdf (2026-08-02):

# The ESP32-S3 & MicroPython

### A Story-Driven Guide for the BikeWheel POV Project

This guide explains how the XIAO ESP32-S3 microcontroller works, why certain pins were chosen for SPI, hall sensor, and WiFi, and how MicroPython sits on top of it all to bring your code to life. No prior electronics degree required.

# Chapter 1: What Is the ESP32-S3?

Imagine a very small, very capable computer that fits on your fingernail. That's the ESP32-S3. It's a microcontroller — a chip that contains a processor, memory, and a bunch of input/output pins, all in one tiny package. It was designed by a Chinese company called Espressif and is used in everything from smart home devices to industrial sensors to, in your case, a spinning LED bike wheel.

## What's Inside the Chip?

The ESP32-S3 has several key components all baked into a single chip:

Component | What it does | Analogy
Dual-core CPU (Xtensa LX7) | Runs your code at up to 240MHz | The brain — thinks fast
512KB SRAM | Working memory — holds variables while code runs | Your desk — stuff you're currently working on
384KB ROM | Stores bootloader — the code that starts everything up | The startup manual you can't change
8MB Flash (on XIAO) | Stores your Python files permanently | Your hard drive
WiFi radio | 2.4GHz 802.11 b/g/n — runs your BikeWheel hotspot | Built-in phone radio
Bluetooth 5.0 | Short range wireless (not used in your project) | Optional walkie-talkie
45 GPIO pins | Connect to LEDs, sensors, batteries — the real world | Hands reaching out to the world

## What Makes the S3 Special?

The "S3" variant was released in 2021 and brought some important upgrades over earlier ESP32 chips. Most importantly for your project, it has a much faster CPU (240MHz dual core), better SPI hardware, and native USB support — which is why you can plug the XIAO directly into your laptop and Thonny can talk to it without needing a separate USB-to-serial adapter chip.

## The XIAO Form Factor

Seeed Studio's XIAO ESP32-S3 is a particular board design around the ESP32-S3 chip. At just 21x17mm it is one of the smallest ESP32-S3 boards available. This is why it fits in your hub enclosure where a standard development board never would. It breaks out 11 GPIO pins, has a USB-C port, a built-in antenna, a charge LED, and a reset button — everything you need, nothing you don't.

# Chapter 2: GPIO Pins — The Hands of the Chip

GPIO stands for General Purpose Input/Output. These are the physical pins on the chip that connect to the outside world — your LEDs, your hall sensor, your power rails. Think of them as the chip's hands. Some hands can only receive (input), some can only give (output), and most can do both.

## Input vs Output

When a pin is configured as an INPUT, the chip reads a voltage on that pin and decides if it's HIGH (3.3V = logical 1) or LOW (0V = logical 0). Your hall sensor output connects to an input pin — the chip reads whether the magnet is present or not.

When a pin is configured as an OUTPUT, the chip drives the pin to 3.3V or 0V. This is how it sends data and clock signals to the LED strip — by rapidly toggling output pins high and low in precise patterns.

## Pull-up and Pull-down Resistors

Here's a subtle but important concept. When nothing is connected to an input pin, what does it read? The answer is "garbage" — it floats around randomly. To prevent this, you can activate an internal resistor that gently pulls the pin to a known state.

A PULL_UP resistor connects the pin to 3.3V through a large resistor (~45k ohms). So the pin reads HIGH (1) by default, and only goes LOW (0) when something actively pulls it to ground. This is exactly why your hall sensor circuit works: the pin sits at 1 normally, and drops to 0 when the magnet passes. In MicroPython:

pin = Pin(4, Pin.IN, Pin.PULL_UP)

## The XIAO ESP32-S3 Pinout

The XIAO has 11 exposed GPIO pins. Here is every pin and what it does in your project:

XIAO Label | GPIO # | Your Project | Why This Pin
5V | — | Power to LEDs + MT3608 output | Only 5V power pin on board
GND | — | Common ground for all components | Ground reference
3V3 | — | Hall sensor VCC | 3.3V — matches sensor rating
D0 | GPIO1 | Available | —
D1 | GPIO2 | Available (status LED future) | General purpose output
D2 | GPIO3 | Available | —
D3 | GPIO4 | Hall sensor OUT | See Chapter 3 — interrupt capable
D4 | GPIO5 | Available (I2C SDA) | —
D5 | GPIO6 | Available (I2C SCL) | —

D8 | GPIO7 | SK9822 Clock (CI / Yellow wire) | Hardware SPI SCK — see Chapter 4
D9 | GPIO8 | Available | —
D10 | GPIO9 | SK9822 Data (DI / Green wire) | Hardware SPI MOSI — see Chapter 4
Purple rows = SPI pins (hardware accelerated). Yellow row = interrupt-capable pin used for hall sensor.

# Chapter 3: Interrupts — How the Hall Sensor Works

## The Problem With Polling

Imagine you're cooking dinner and waiting for a friend to knock on the door. You could check the door every 5 seconds — walk to the door, check, walk back, cook, walk to the door, check, walk back... This is called polling and it wastes most of your time walking to the door for nothing.

Your POV loop has the same problem. It's busy displaying 60 columns of LEDs with microsecond precision. It cannot stop every few milliseconds to check if the hall sensor fired — that would ruin the timing and blur the image.

## The Solution: Hardware Interrupts

An interrupt is the solution. Instead of your code checking the sensor, you tell the hardware: "the moment that pin goes from HIGH to LOW, stop everything and run this function immediately." Then go back to what you were doing.

It's like installing a doorbell instead of checking the door every 5 seconds. You cook normally. The doorbell rings. You answer it. You go back to cooking. The chip's hardware handles this at a level below your Python code — faster and more reliable than anything you could write in software.

## Why GPIO4 (D3)?

On the ESP32-S3, almost all GPIO pins are capable of generating interrupts. GPIO4 was chosen simply because it's available, clearly labeled as D3 on the XIAO, and not needed for SPI or any other dedicated function. There's nothing magic about GPIO4 specifically — any free pin would work.

## The Falling Edge

We configure the interrupt to trigger on a FALLING EDGE — the moment the signal transitions from HIGH (1) to LOW (0). That's the exact instant the magnet passes the sensor. Not the rising edge (LOW to HIGH, when the magnet moves away), not a level trigger (fires continuously while LOW) — just that one precise moment of transition. In MicroPython:

pin.irq(trigger=Pin.IRQ_FALLING, handler=self._on_trigger)

## The 5ms Debounce

Physical magnets and sensors produce noisy signals. When the magnet passes, the signal doesn't cleanly go LOW once — it can bounce up and down several times in a few microseconds before settling. Without protection, this looks like multiple rapid triggers and your rotation count would be wrong.

The debounce check (diff > 5000 microseconds) ignores any trigger that happens within 5ms of the previous one. At maximum wheel speed — say 200 RPM — one full rotation takes 300,000 microseconds. So any trigger within 5ms of the last one is definitely noise, not a real rotation.

# Chapter 4: SPI — How Data Gets to the LEDs

## What is SPI?

SPI stands for Serial Peripheral Interface. It's a communication protocol — a set of rules for how two devices talk to each other. SPI uses two data wires and is extremely fast, which is why the SK9822 LEDs use it.

Think of SPI like a very fast conveyor belt with a timing light. The clock wire flashes a light at regular intervals. Every time the light flashes, the data wire carries one bit of information. The LED strip reads each bit in sync with each clock flash. This synchronization is what makes SPI so reliable — both sides always agree on exactly when to read the data.

## The Two SPI Wires

Wire | SPI Name | XIAO Pin | SK9822 Label | Color | What it does
Clock | SCK | D8 / GPIO7 | CI (Clock In) | Yellow | Beats like a metronome — one beat per bit
Data | MOSI | D10 / GPIO9 | DI (Data In) | Green | Carries the actual color data — one bit per beat

## Why Hardware SPI? (GPIO7 and GPIO9)

The ESP32-S3 has dedicated SPI hardware built into the chip — dedicated circuits that handle the clock and data signals automatically at up to 80MHz. GPIO7 and GPIO9 are directly wired to these hardware SPI circuits.

You could theoretically use any GPIO pins for SPI by manually toggling them in Python code — this is called "bit-banging." But there's a critical problem: MicroPython is an interpreted language running on top of an operating system. It cannot toggle pins fast enough or consistently enough for reliable high-speed SPI.

By using GPIO7 and GPIO9 (the hardware SPI pins), you hand the job to dedicated silicon circuits that run independently of your Python code at 8 million bits per second. Your Python just says "send this data" and the hardware does the rest instantly. This is why your full strip of 72 LEDs updates in about 288 microseconds — fast enough for precise POV timing.

Key insight: GPIO7 and GPIO9 were chosen not because of the numbers, but because they are physically wired inside the chip to the hardware SPI peripheral. Using any other pins for SPI would require slow, unreliable software bit-banging.

## SPI Mode 0 — Why polarity=0, phase=0?

SPI has four modes (0-3) that define when data is valid relative to the clock. The SK9822 datasheet specifies Mode 0: clock idles LOW (polarity=0) and data is read on the rising edge (phase=0). These are not arbitrary choices — they must match what the LED chip expects or the data gets corrupted.

## The SK9822 Frame Format

The SK9822 has a very specific format for how color data must be sent. For every LED update, the XIAO sends a stream of bytes in this exact order:

Section | Bytes | Content | Purpose
Start frame | 4 bytes | 00 00 00 00 | Signals new data coming — "attention!"
LED 1 frame | 4 bytes | FF bb gg rr | Brightness + Blue + Green + Red for LED 1
LED 2 frame | 4 bytes | FF bb gg rr | Data for LED 2
... (repeat) | 4 bytes each | ... | One frame per LED
End frame | 4+ bytes | FF FF FF... | Clocks data through to last LED in chain

Note: SK9822 sends color in Blue-Green-Red order, NOT Red-Green-Blue. This is why apa102.py packs bytes as [brightness, b, g, r] not [brightness, r, g, b].

# Chapter 5: MicroPython — The Language Layer

## What is MicroPython?

MicroPython is a lean, efficient implementation of Python 3 designed to run directly on microcontrollers. Regular Python runs on your laptop with gigabytes of RAM and a full operating system underneath it. MicroPython runs on a chip with 512KB of RAM and no operating system — just bare metal.

Think of it like this: regular Python is a luxury car with all the amenities. MicroPython is a stripped-down racing car — lighter, faster to start, runs on less fuel, but still recognizably a car that you drive the same way.

## The Software Stack

When you power on the XIAO, here is exactly what happens in order:

Layer | What it is | What it does
1. Hardware | ESP32-S3 silicon chip | Electricity flows, transistors switch
2. Bootloader | Stored in ROM (read-only) | Initialises hardware, finds MicroPython in flash
3. MicroPython VMStored in your 8MB flash | | Interprets Python bytecode, manages memory
4. boot.py | Your file in flash | Runs first — WiFi setup, startup config
5. main.py | Your file in flash | Runs second — your actual program
6. Your modules | apa102.py, hall_sync.py etc | Imported by main.py as needed

## The machine Module — Talking to Hardware

MicroPython's most important feature for hardware projects is the machine module. This is a special module that provides direct access to the chip's hardware peripherals from Python. Without it, you'd need to write C code to access the GPIO pins and SPI bus.

Class | What it controls | Used in your project
machine.Pin | Individual GPIO pins | Hall sensor input with pull-up and interrupt
machine.SPI | Hardware SPI bus | Sending color data to SK9822 LEDs at 8MHz
machine.I2C | I2C communication bus | Not used yet — available for sensors
machine.PWM | Pulse width modulation | Not used — could control motor speed etc
machine.Timer | Hardware timers | Not used — interrupts handle timing instead
machine.ADC | Analog to digital converter | Could read battery voltage in future

## Interpreted vs Compiled — Why MicroPython is Slower

Regular C code that runs on microcontrollers is compiled — translated directly into machine instructions before it runs. Every line of C becomes raw binary instructions that the CPU executes directly.

MicroPython is interpreted — your Python code is read line by line at runtime and translated on the fly. This is slower, but not by as much as you'd think for most tasks. Where it matters is timing-critical operations like bit-banging SPI.

This is exactly why your project uses hardware SPI (machine.SPI) instead of manually toggling pins in Python. The hardware SPI runs in dedicated silicon independent of the Python interpreter. Your Python just triggers it and the hardware does the rest at full speed.

## ticks_us() — Microsecond Timing

The POV column timing requires microsecond precision — each column must display for exactly the right number of microseconds or the image blurs. MicroPython provides time.ticks_us() which returns the current time in microseconds.

One subtlety: the tick counter is not infinite. It wraps around after a while (about 17 minutes on ESP32). This is why the code uses time.ticks_diff() to calculate time differences instead of simple subtraction. ticks_diff() handles the wrap-around correctly so timing never breaks after 17 minutes of running.

# Chapter 6: WiFi — The Built-in Radio

One of the most remarkable things about the ESP32-S3 is that a full 2.4GHz WiFi radio is built directly into the chip at no extra cost or size. The same silicon that runs your Python code also broadcasts a WiFi hotspot that your Android app connects to.

## Access Point vs Station Mode

The ESP32 WiFi can operate in two modes. In Station mode (STA_IF) it behaves like your phone — connecting to an existing WiFi network like your home router. In Access Point mode (AP_IF) it creates its own network that other devices connect to. This is what your project uses, because on the Burning Man playa there is no WiFi network to connect to. The wheel IS the WiFi network.

## The Web Server on Port 80

Your Android app sends HTTP requests to http://192.168.4.1/pov or /safety or /brightness/25 etc. The XIAO's web server listens on port 80 (the standard HTTP port) and responds to these requests. It's a stripped-down version of what a web server like Apache or Nginx does — but implemented in about 20 lines of Python instead of millions.

The key design choice is non-blocking mode. The socket is set to setblocking(False) so the web server check never freezes the main loop. The POV timing loop can keep running while the WiFi waits for requests. Without this, checking for web requests would pause the LEDs and ruin the POV effect.

# Chapter 7: Power — Keeping Everything Running

The ESP32-S3 operates at 3.3V logic level. This means all its GPIO pins output 3.3V for HIGH and 0V for LOW. However, your LED strip needs 5V to operate correctly. This mismatch is why the MT3608 boost converter exists.

## The Two Circuits

Circuit | Path | Purpose
Riding (power) | LiPo 3.7V → MT3608 → 5.07V → XIAO 5V pin + LED strip | Powers everything while riding
Charging | USB-C wall charger → TP4056 → LiPo battery | Charges battery at camp overnight

Critical rule: the TP4056 charger is NEVER in the riding power circuit. It connects only to the battery for charging. Mixing them would damage the TP4056.

## Voltage Logic Levels and the LED Strip

The XIAO outputs 3.3V logic on its GPIO pins. The SK9822 technically expects 5V logic signals on DI and CI. In practice, the SK9822 accepts 3.3V signals as valid HIGH — which is why the project works without a level shifter. If you ever experience unreliable first-LED behavior, a 330 ohm resistor on the DI line or a proper logic level shifter would fix it.

## Current Budget

At full brightness, each SK9822 LED draws about 60mA (20mA per color channel). With 72 LEDs that's theoretically 4.3A. In practice, your POV display never lights all LEDs at full white simultaneously — typical current draw is closer to 500mA-1A for colorful animation frames. The LiPo 2000mAh battery gives you roughly 2-4 hours of riding on a single charge.

# Quick Reference Card

## Pin Summary

What | XIAO Label | GPIO | Why
LED Clock (CI) | D8 | GPIO7 | Hardware SPI SCK pin
LED Data (DI) | D10 | GPIO9 | Hardware SPI MOSI pin
Hall Sensor OUT | D3 | GPIO4 | Interrupt capable, free pin
Hall Sensor VCC | 3V3 | — | 3.3V matches A3144 rating
LED Strip 5V | 5V | — | Only 5V output on board
All GND | GND | — | Common ground

## Key Concepts Cheat Sheet

GPIO — General Purpose Input/Output — the physical pins on the chip that connect to the real world
SPI — Serial Peripheral Interface — two-wire protocol (clock + data) used to drive the SK9822 LEDs
Hardware SPI — SPI handled by dedicated silicon circuits at up to 80MHz — much faster than software
Interrupt — Hardware mechanism that fires a function instantly when a pin changes — how hall sensor works
Pull-up resistor — Holds a pin HIGH by default — hall sensor pulls it LOW when magnet passes Falling edge — The moment a pin transitions HIGH to LOW — when the interrupt fires Debounce — Ignoring triggers within 5ms of each other — filters out electrical noise
AP mode — Access Point — XIAO creates its own WiFi network for your phone to connect to Non-blocking socket — Web server that checks for requests without freezing — critical for POV timing
ticks_us() — MicroPython microsecond timer — used for precise POV column timing MicroPython VM — The interpreter that runs your .py files on the bare metal chip
boot.py / main.py — Auto-run files — boot.py first, then main.py, every time the chip powers on

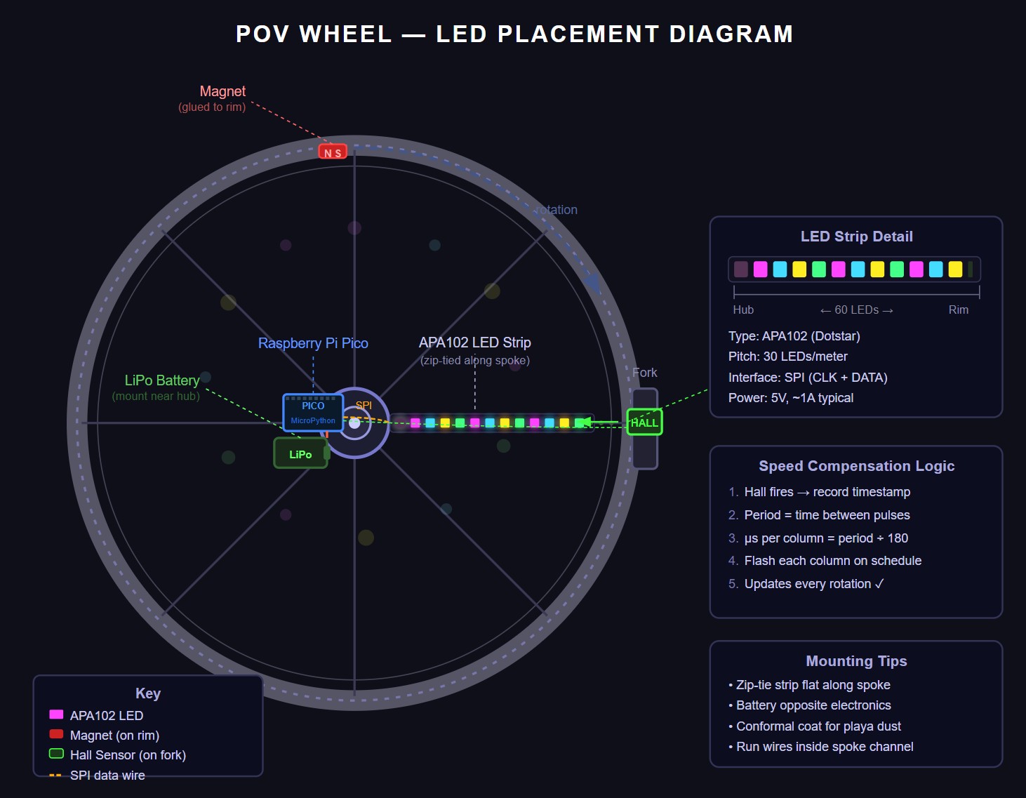
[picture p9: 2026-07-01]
Guides/PoV Wheel.jpg

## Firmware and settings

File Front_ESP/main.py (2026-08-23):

"""
main.py — Front Wheel XIAO
============================
- 216 LEDs (8 strips x 27 LEDs)
- POV timing engine driven by hall sensor
- WiFi AP (BikeWheel / burningman)
- Serves PWA control page at http://192.168.4.1
- ESP-NOW broadcasts RPM to rear XIAO

Endpoints:
  GET /          → serves index.html (PWA)
  GET /on        → LEDs on
  GET /off       → LEDs off
  GET /next      → next animation frame
  GET /brightness/N → set brightness 1-31
  GET /ping      → health check
  GET /status    → JSON {leds_on, rpm, is_spinning}

Upload to front XIAO:
  main.py, apa102.py, hall_sync.py, frames.py, espnow_tx.py, index.html
"""

import time
import network
import socket
import json
from apa102 import APA102
from hall_sync import HallSync
from frames import make_rainbow_frame, make_cross_frame
from espnow_tx import ESPNowBroadcaster

# ── Config ────────────────────────────────────────────────────────────────────
NUM_LEDS    = 216
NUM_COLUMNS = 60
BRIGHTNESS  = 8

# ── Hardware ──────────────────────────────────────────────────────────────────
strip = APA102(num_leds=NUM_LEDS, brightness=BRIGHTNESS)
hall  = HallSync(pin_num=4)

# ── ESP-NOW ───────────────────────────────────────────────────────────────────
broadcaster = ESPNowBroadcaster()

# ── WiFi AP ───────────────────────────────────────────────────────────────────
ap = network.WLAN(network.AP_IF)
ap.active(True)
ap.config(essid='BikeWheel', password='burningman', authmode=3)
print('WiFi AP:', ap.ifconfig()[0])

# ── Web server ────────────────────────────────────────────────────────────────
server = socket.socket()
server.setsockopt(socket.SOL_SOCKET, socket.SO_REUSEADDR, 1)
server.bind(('0.0.0.0', 80))
server.listen(1)
server.setblocking(False)

# ── Load PWA HTML ─────────────────────────────────────────────────────────────
try:
    with open('index.html', 'r') as f:
        INDEX_HTML = f.read()
    print('PWA loaded')
except:
    INDEX_HTML = '<h1>BikeWheel</h1><a href="/on">ON</a> <a href="/off">OFF</a>'
    print('index.html not found — using fallback')

# ── State ─────────────────────────────────────────────────────────────────────
leds_on            = True
current_frame_idx  = 0
rot_at_last_frame  = 0
ROTATIONS_PER_FRAME = 5

# ── Build frames ──────────────────────────────────────────────────────────────
FRAMES = [
    make_rainbow_frame(NUM_COLUMNS, NUM_LEDS),
    make_cross_frame(NUM_COLUMNS, NUM_LEDS),
]

# ── Web handler ───────────────────────────────────────────────────────────────
def handle_web():
    global leds_on, current_frame_idx, BRIGHTNESS

    try:
        conn, addr = server.accept()
        req = conn.recv(2048).decode()
        path = req.split(' ')[1] if ' ' in req else '/'

        # ── Serve PWA ──────────────────────────────────────────────────
        if path == '/' or path == '/index.html':
            conn.send(b'HTTP/1.1 200 OK\r\nContent-Type: text/html\r\n\r\n')
            conn.send(INDEX_HTML.encode())

        # ── LED on ─────────────────────────────────────────────────────
        elif path == '/on':
            leds_on = True
            strip.show([(0, 255, 0)] * NUM_LEDS)
            time.sleep_ms(200)
            print('ON')
            conn.send(b'HTTP/1.1 200 OK\r\nContent-Type: application/json\r\n\r\n{"ok":true}')

        # ── LED off ────────────────────────────────────────────────────
        elif path == '/off':
            leds_on = False
            strip.off()
            print('OFF')
            conn.send(b'HTTP/1.1 200 OK\r\nContent-Type: application/json\r\n\r\n{"ok":true}')

        # ── Next pattern ───────────────────────────────────────────────
        elif path == '/next':
            current_frame_idx = (current_frame_idx + 1) % len(FRAMES)
            print('Frame:', current_frame_idx)
            conn.send(b'HTTP/1.1 200 OK\r\nContent-Type: application/json\r\n\r\n{"ok":true}')

        # ── Brightness /brightness/N ───────────────────────────────────
        elif path.startswith('/brightness/'):
            try:
                val = int(path.split('/')[-1])
                BRIGHTNESS = max(1, min(31, val))
                strip.brightness = BRIGHTNESS
                print('Brightness:', BRIGHTNESS)
            except:
                pass
            conn.send(b'HTTP/1.1 200 OK\r\nContent-Type: application/json\r\n\r\n{"ok":true}')

        # ── Ping ───────────────────────────────────────────────────────
        elif path == '/ping':
            conn.send(b'HTTP/1.1 200 OK\r\nContent-Type: application/json\r\n\r\n{"pong":true}')

        # ── Status ─────────────────────────────────────────────────────
        elif path == '/status':
            rpm = hall.get_rpm()
            resp = json.dumps({
                "leds_on": leds_on,
                "rpm": round(rpm, 1),
                "is_spinning": hall.is_spinning(),
                "brightness": BRIGHTNESS,
                "frame": current_frame_idx
            })
            conn.send(('HTTP/1.1 200 OK\r\nContent-Type: application/json\r\n\r\n' + resp).encode())

        else:
            conn.send(b'HTTP/1.1 404 Not Found\r\n\r\nNot found')

        conn.close()
    except:
        pass

# ── Main loop ─────────────────────────────────────────────────────────────────
print('Front wheel ready —', NUM_LEDS, 'LEDs')
print('Connect to WiFi: BikeWheel / burningman')
print('Open browser: http://192.168.4.1')

last_web_check = time.ticks_ms()

while True:

    now = time.ticks_ms()
    if time.ticks_diff(now, last_web_check) > 100:
        handle_web()
        last_web_check = now

    # Broadcast RPM to rear XIAO
    broadcaster.send(
        rpm=hall.get_rpm(),
        period_us=hall.get_period(),
        is_spinning=hall.is_spinning()
    )

    # Safety — LEDs off when not spinning or switched off
    if not leds_on or not hall.is_spinning():
        strip.off()
        time.sleep_ms(20)
        continue

    period = hall.get_period()
    if period == 0:
        time.sleep_ms(10)
        continue

    # Advance frame every N rotations
    if hall.rotation_count - rot_at_last_frame >= ROTATIONS_PER_FRAME:
        current_frame_idx = (current_frame_idx + 1) % len(FRAMES)
        rot_at_last_frame = hall.rotation_count

    # POV column display
    column_dur = period // NUM_COLUMNS
    frame = FRAMES[current_frame_idx]

    for col in range(NUM_COLUMNS):
        t0 = time.ticks_us()
        strip.show(frame[col])
        elapsed = time.ticks_diff(time.ticks_us(), t0)
        remaining = column_dur - elapsed
        if remaining > 0:
            time.sleep_us(remaining)

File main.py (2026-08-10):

# *** LOADS ALL THE LIBRARIES NEEDED ***
# Network and Socket are for WiFi. 
# APA102 and HallSync are your custom files on the XIAO.
# frames.py contains all animation frame data.

import time
import network
import socket
from machine import Pin
from apa102 import APA102
from hall_sync import HallSync
from frames import make_test_frame


# *** HARDWARE INITIALIZATION ***
# Front Wheel Architecture — 4 arms, 2 faces per arm, 8 strips total
# Each strip has 27 LEDs at 144 LED/meter = 187mm (~7.4") per arm
# Total: 27 LEDs x 8 strips = 216 LEDs
#
# Daisy chain order:
# ESP Box → A1(1-27) → B1(28-54) → A2(55-81) → B2(82-108)
#         → A3(109-135) → B3(136-162) → A4(163-189) → B4(190-216)
#
# A = Front face (hub → rim)
# B = Back face (rim → hub) — columns reversed in frames.py
#
# For 30 LED/meter rear wheel:
# 10" Spokes has 14 LEDs (7/side)

# ****** LED CHANGE HERE — THIS IS THE ONLY LINE YOU NEED TO CHANGE WHEN SWAPPING STRIPS ******
NUM_LEDS = 216  # 27 LEDs x 8 strips (4 arms x 2 faces) — change this ONE value only

NUM_COLUMNS = 60  # How many angular slices per rotation — do not change

strip = APA102(num_leds=NUM_LEDS, brightness=8)  # brightness=8 — plenty bright on dark playa, saves battery
hall = HallSync(pin_num=4)  # Hall sensor on GPIO4 (D3 on XIAO)


# *** AP CONFIGURATION / START WI-FI HOTSPOT ***
# AP_IF means it is in Access Point mode — the XIAO IS the hotspot, other devices connect TO it
# STA_IF would mean the XIAO connects TO an existing WiFi network (not used here)
# ap.active(True) activates the access point. True = on, False = off.
# ap.config sets the essid, the password and the authentication mode. 3 means WPA2.
# By default the XIAO's IP address is 192.168.4.1
# To change the IP address, use ap.ifconfig():
# e.g: ap.ifconfig(('192.168.1.1', '255.255.255.0', '192.168.1.1', '8.8.8.8'))

ap = network.WLAN(network.AP_IF)
ap.active(True)
ap.config(essid='BikeWheel', password='burningman', authmode=3)
print('WiFi started:', ap.ifconfig()[0])


# *** WEB SERVER SETUP ***
# Opens a simple HTTP server on port 80.
# When a request comes in, handle_web() checks for /on or /off and responds.

server = socket.socket()  # Creates a network socket — like picking up a phone before dialing

server.setsockopt(socket.SOL_SOCKET, socket.SO_REUSEADDR, 1)
# SO_REUSEADDR — crash recovery safety net.
# If the XIAO reboots, port 80 might still be marked "in use" by the old session.
# This line says: if the port is still reserved, grab it anyway.

server.bind(('0.0.0.0', 80))
# 0.0.0.0 means "listen on all available interfaces" — accept connections from anyone on the network.
# Port 80 is the standard HTTP port — why the app connects with just http://192.168.4.1 (no port number needed).

server.listen(1)  # Start listening. 1 = only keep 1 connection waiting in queue at a time.

server.setblocking(False)
# Non-blocking mode — server.accept() checks instantly instead of freezing to wait.
# If no connection is waiting it throws an exception — caught by try/except in handle_web().
# Critical for POV — we can't freeze the timing loop waiting for web requests.


# *** STATE VARIABLES ***
leds_on = True           # Master on/off switch controlled by web server
current_frame = 0        # Which animation frame is currently showing
rot_at_last_frame = 0    # Rotation count when we last advanced the frame
ROTATIONS_PER_FRAME = 5  # How many wheel rotations before advancing to next frame


# *** BUILD FRAMES ***
# Passes NUM_COLUMNS and NUM_LEDS to frames.py — single source of truth stays in main.py.
# frames.py handles front/back face reversal automatically.
# Add more frames here as you build them (circle, square, cross etc.)
FRAMES = [make_test_frame(NUM_COLUMNS, NUM_LEDS)]


# *** WEB REQUEST HANDLER ***
# Called every 100ms from the main loop.
# Checks for incoming HTTP requests and handles /on and /off commands.
# Uses NUM_LEDS so flash colors are always correct regardless of strip size.
def handle_web():
    global leds_on
    try:
        conn, addr = server.accept()
        req = conn.recv(1024).decode()
        if '/on' in req:
            leds_on = True
            strip.show([(0, 255, 0)] * NUM_LEDS)  # Flash green — NUM_LEDS updates automatically
            time.sleep_ms(300)
            print('LEDs ON')
        elif '/off' in req:
            leds_on = False
            strip.show([(255, 0, 0)] * NUM_LEDS)  # Flash red — NUM_LEDS updates automatically
            time.sleep_ms(300)
            strip.off()
            print('LEDs OFF')
        conn.send(b'HTTP/1.1 200 OK\r\n\r\nOK')
        conn.close()
    except:
        pass  # No connection waiting — non-blocking mode throws exception, we ignore it and move on


print('Starting main loop...')
last_web_check = time.ticks_ms()
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

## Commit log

2026-07-01 Create README.md for Burning Man LED Generator
    Added a README file with project details and file descriptions.
2026-07-01 Added BOM and updated README
2026-07-02 Added gitignore and ESP32S3 firmware to repo
2026-07-03 Added webserver: 192.168.4.1 BikeWheel/burningman
    [main.py]
2026-07-03 sample code, Thonny code, LED Pinout
2026-07-07 Magnet + LED test code and magnet test code added
2026-07-07 made changes to main.py LEDS flash with magnet
2026-07-23 Tested, ready to mount
2026-07-29 Updated readme updated to 1 bar/wheel
2026-07-30 Comments for apa102.py and updated main.py to define all LEDs in one place. This makes it easier to change the number of LEDs on the bike without having to hunt through the code for all the places th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
2026-07-30 added comments to frames.py and main.py
2026-08-02 added guides + datasheet
    [bikewheel_enclosure.stl]
2026-08-10 Updated files to add 4 LED strips @ 27 LED /strip
2026-08-11 Massive updates to the readme file and wheel.svg
2026-08-21 Updated the pinout image and added some sample code
2026-08-23 Created the system for the esp on both wheels
